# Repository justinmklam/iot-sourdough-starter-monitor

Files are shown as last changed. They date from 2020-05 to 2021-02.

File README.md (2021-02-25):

# IoT Sourdough Starter Monitor

Internet connected smart lid for sourdough starter. Tracks fermentation with distance, temperature, and humidity sensors, and publishes data to the cloud for further data logging and analysis.

Interested in more details? Read the full story on [justinmklam.com](https://www.justinmklam.com/posts/2021/02/levain-monitor/)!

<p align="center">
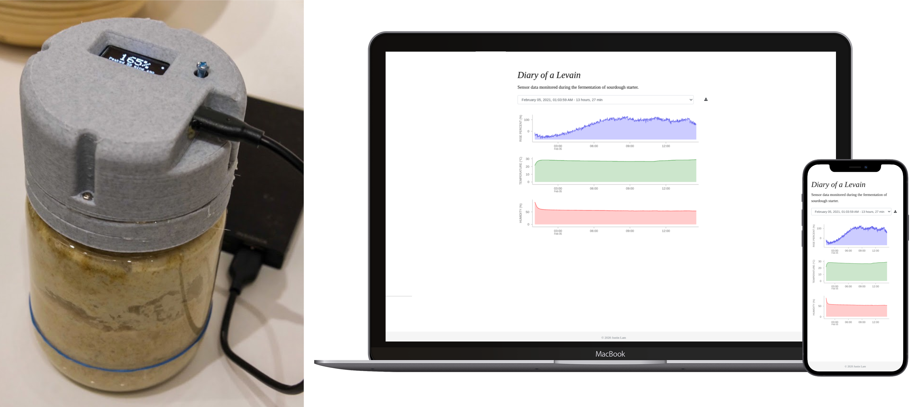
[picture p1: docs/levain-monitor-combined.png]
    <br>
    <i>Sourdough starter monitor (left), web application to view the logged data (right).</i>
</p>

<p align="center">
    <br>
    <i>Three modes of operation: Max rise and time, graph, stats for nerds.</i>
</p>

<p align="center">
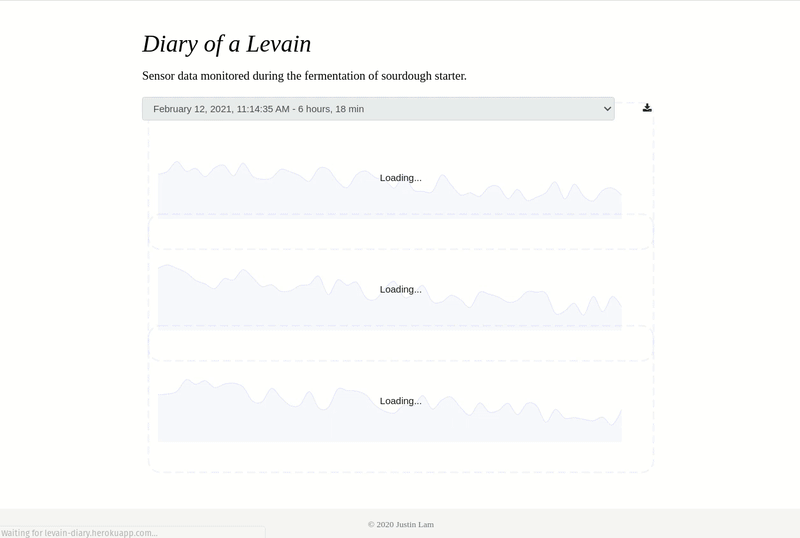
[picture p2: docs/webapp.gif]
    <br>
    <i>Selecting, viewing, and downloading data for a given feeding session.</i>
</p>

## Hardware

- NodeMCU ESP8266 (aka NodeMCU 1.0 ESP-12E)
- DHT22 Temperature and humidity sensor
- VL6180X Time of flight distance sensor
- SSD1306 Monochrome 128x32 I2C OLED display

<p align="center">
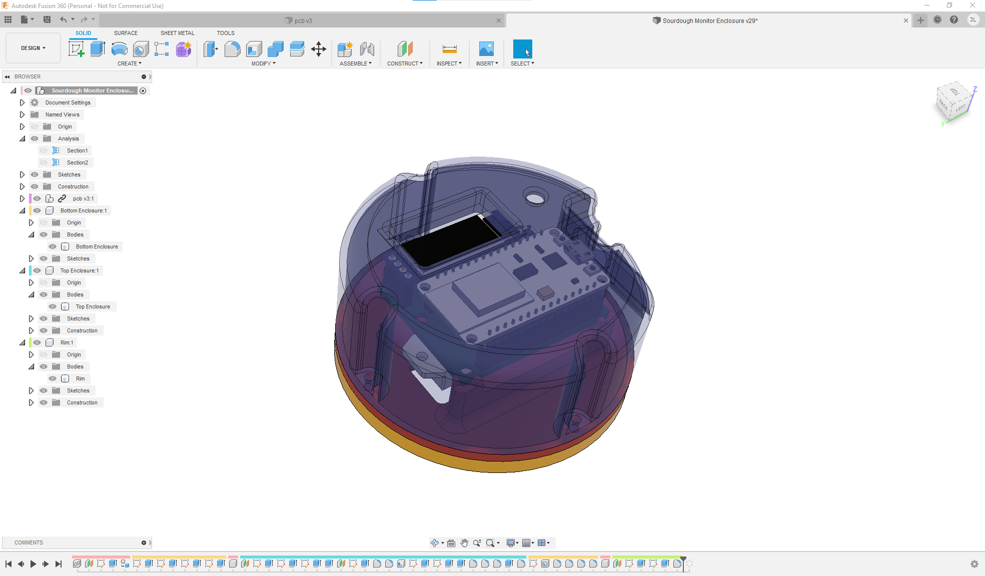
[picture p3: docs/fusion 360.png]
    <br>
    <i>3D printed enclosure (designed in Fusion 360).</i>
</p>

<p align="center">
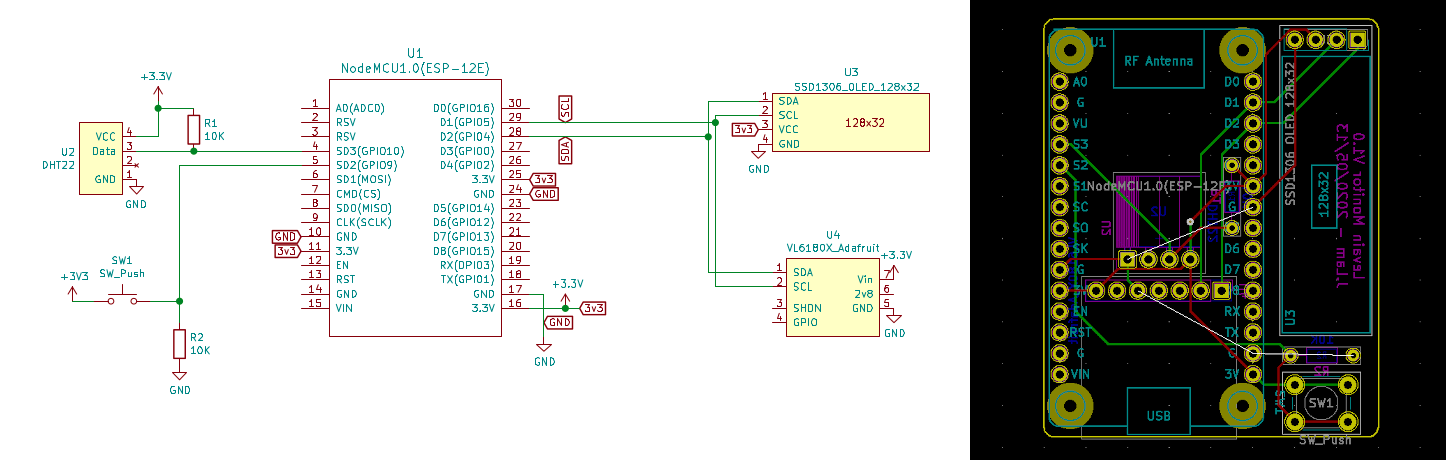
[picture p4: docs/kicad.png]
    <br>
    <i>PCB schematic and layout (designed in KiCad).</i>
</p>

<p align="center">
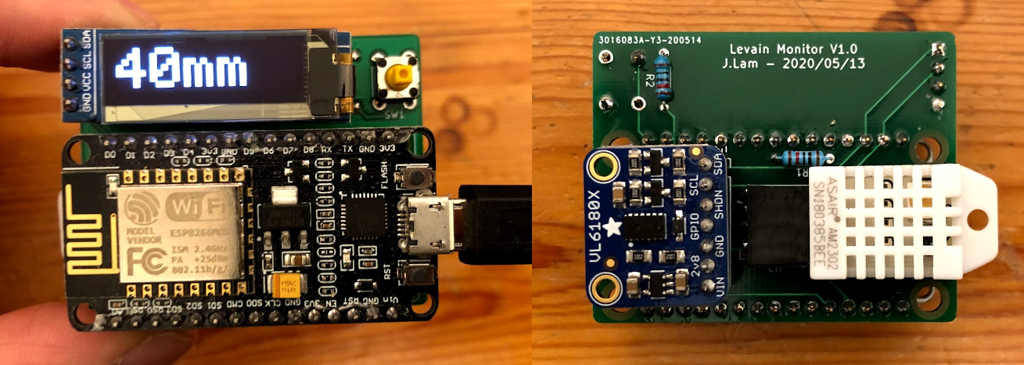
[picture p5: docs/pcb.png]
    <br>
    <i>Assembled PCB.</i>
</p>

## Software

AWS is used as the cloud backend. Data flow is as follows:

- ESP8266 sends sensor data over MQTT
- Kinesis Firehose receives data
- Lambda function puts data from Firehose to S3 on data receive event
- Web app queries S3 data via Athena

## Getting Started

### PlatformIO

This project is built using PlatformIO v5.1.0. To build:

```bash
# Build
pio run

# Build and upload
pio run -t upload
```

To view the serial monitor:

```bash
pio device monitor -b 115200
```

To run the tests:

```bash
# Run tests on device
pio test

# Run tests locally
pio test -e native
```

## Heroku

To deploy the web app to Heroku:

```
git subtree push --prefix webapp heroku master
```

## AWS IoT Certificates

Convert the certificates from AWS to `.der` files, then place them in `data/` (within the project directory).

```bash
openssl x509 -in xxx-certificate.pem.crt -out cert.der -outform DER
openssl rsa -in xxx-private.pem.key -out private.der -outform DER
openssl x509 -in AmazonRootCA1.pem -out ca.der -outform DER
```

Use the following command to upload the files to the SPIFFS filesystem:

```bash
pio run -t uploadfs
```

Alternatively, you may use the [arduino-esp8266fs-plugin](https://github.com/esp8266/arduino-esp8266fs-plugin) to upload the files.

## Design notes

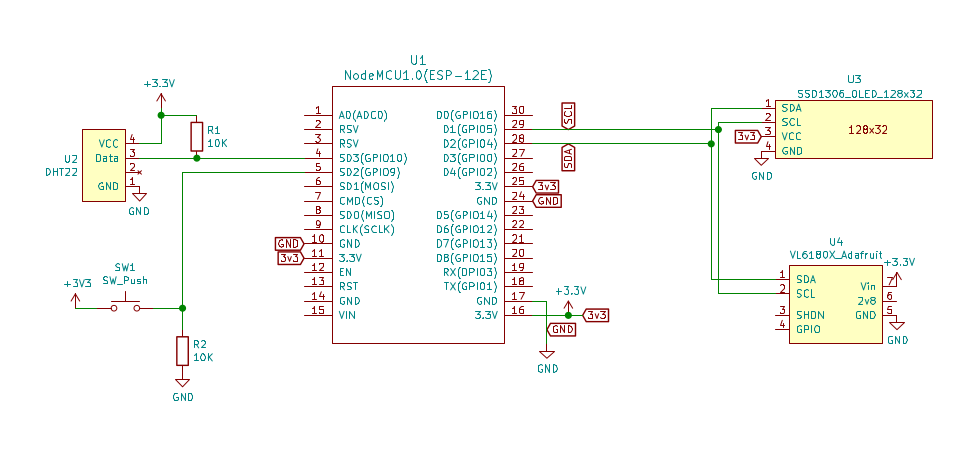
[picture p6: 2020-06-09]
docs/schematic.png

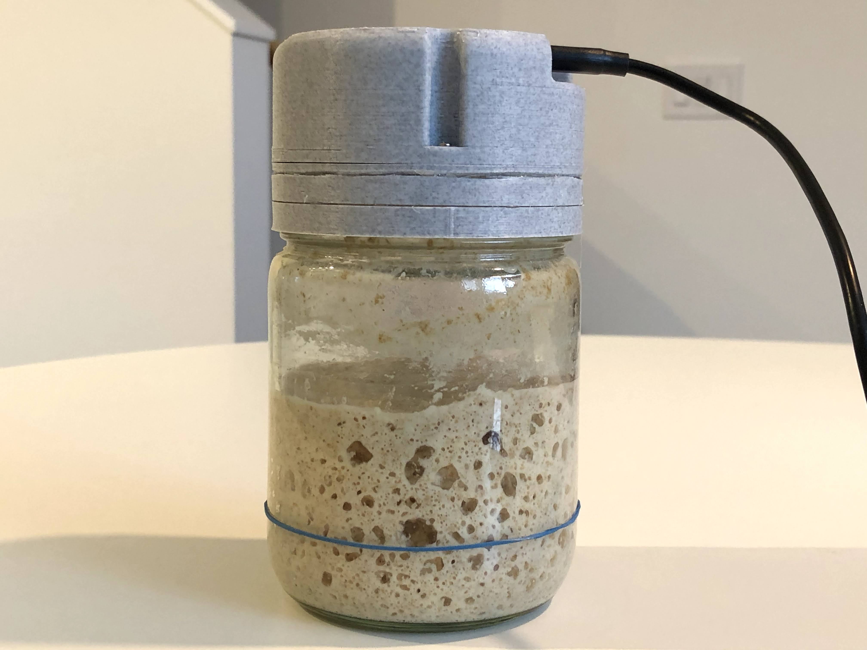
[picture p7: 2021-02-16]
docs/jar2.jpg

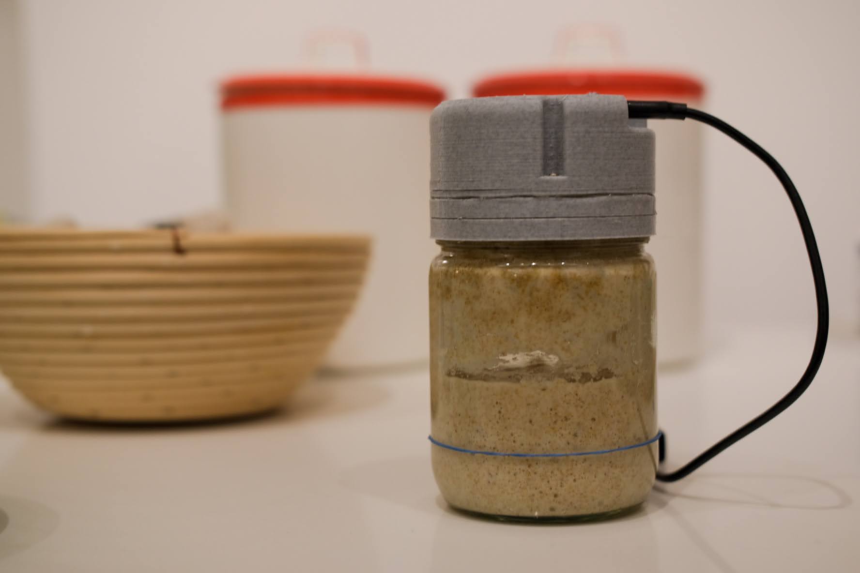
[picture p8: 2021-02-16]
docs/jar3.jpg

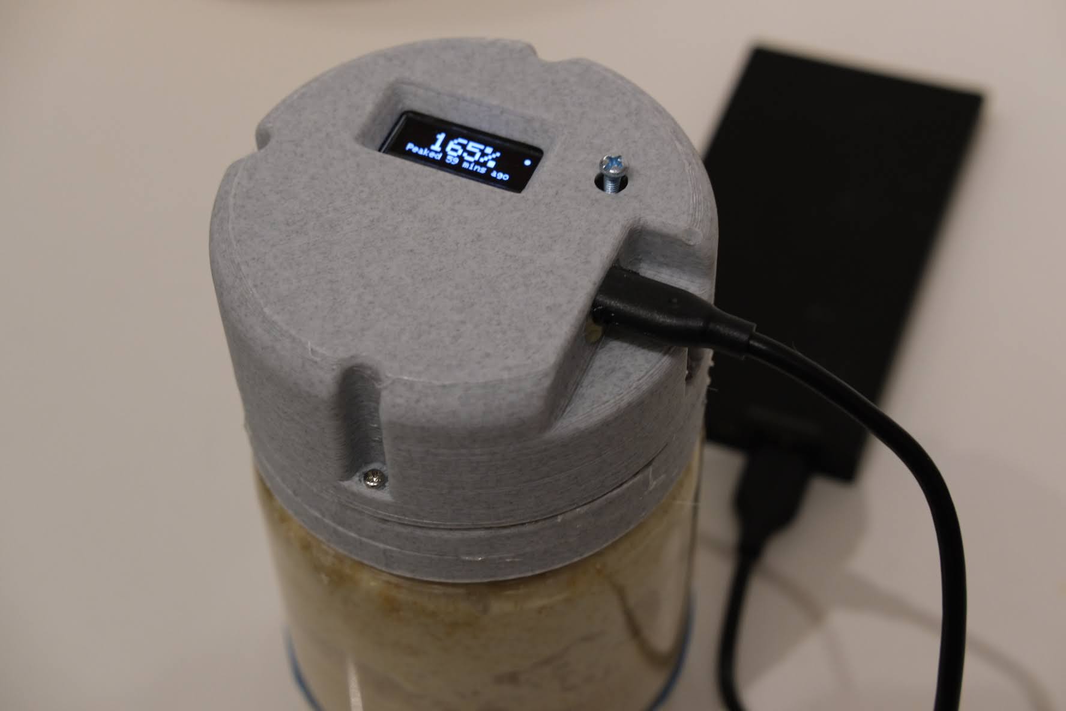
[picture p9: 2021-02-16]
docs/jar1.jpg

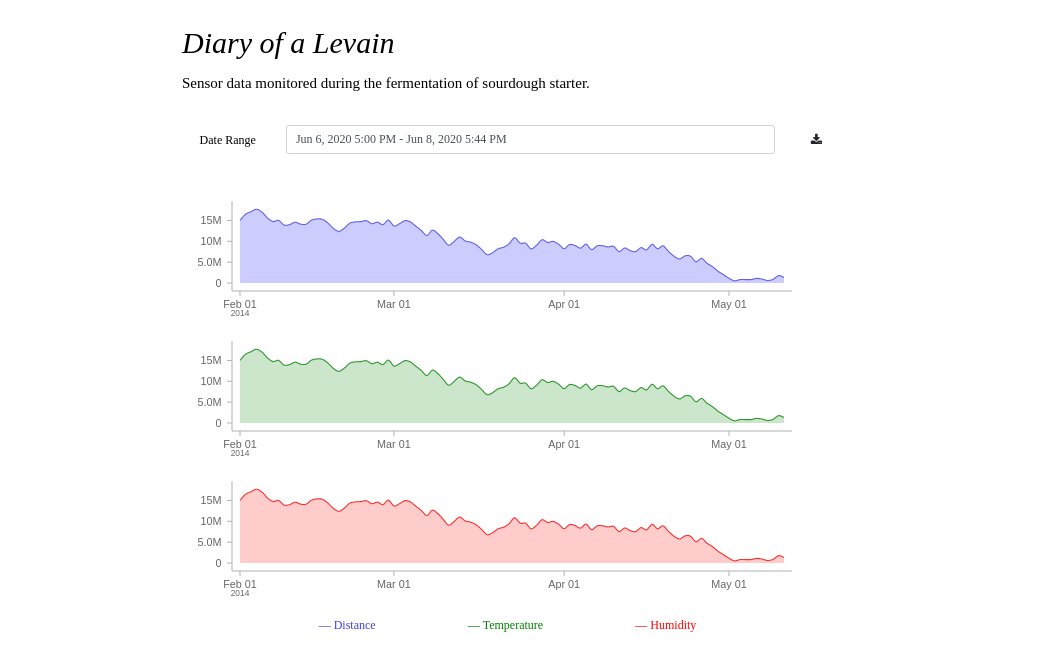
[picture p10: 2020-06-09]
docs/webapp.png

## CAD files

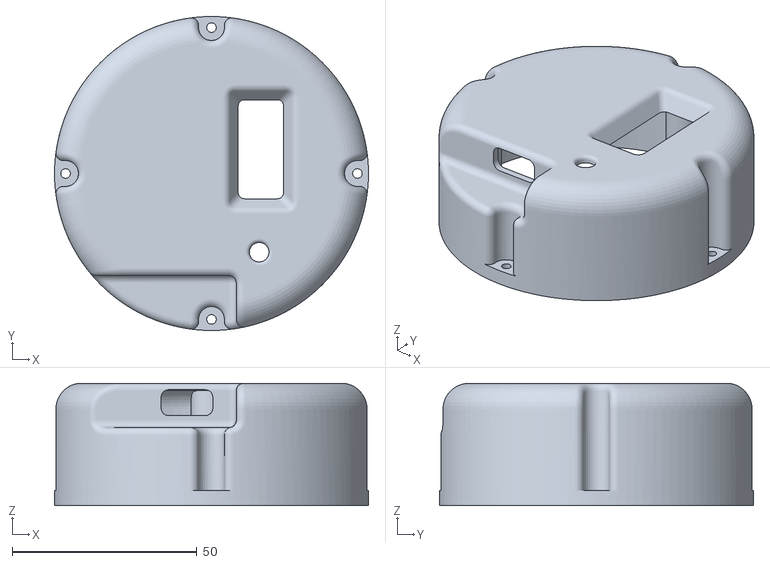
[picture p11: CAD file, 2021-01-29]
cad/Top Enclosure.stl
85.0 x 85.0 x 33.2

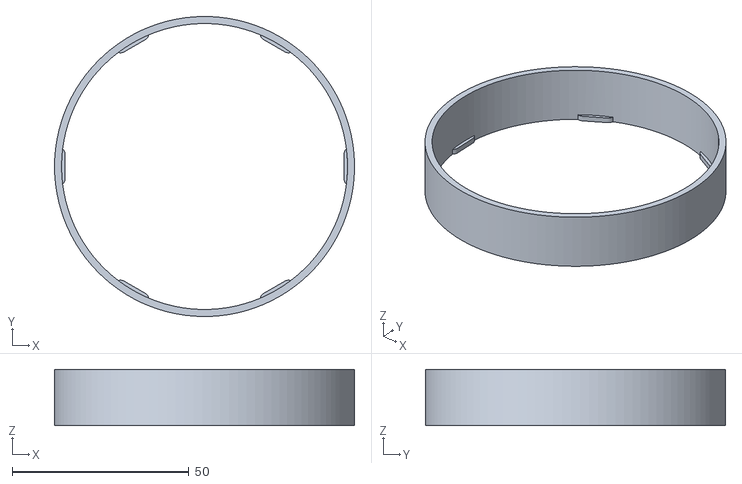
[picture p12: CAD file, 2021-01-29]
cad/Rim.stl
85.0 x 85.0 x 16.0

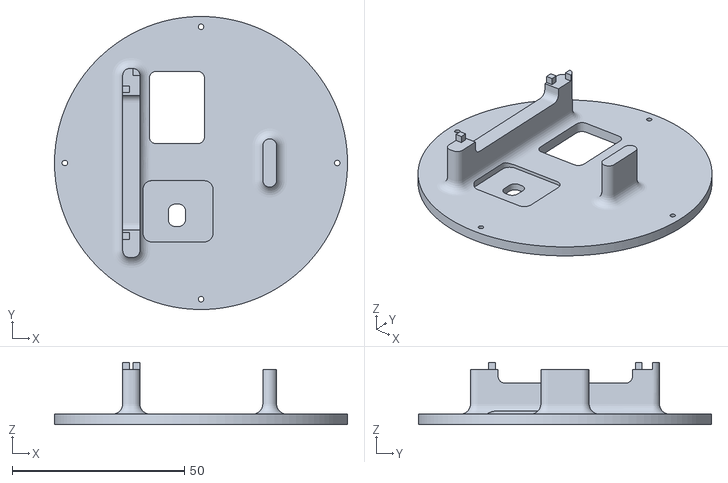
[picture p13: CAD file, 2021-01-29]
cad/Bottom Enclosure.stl
85.0 x 85.0 x 18.0

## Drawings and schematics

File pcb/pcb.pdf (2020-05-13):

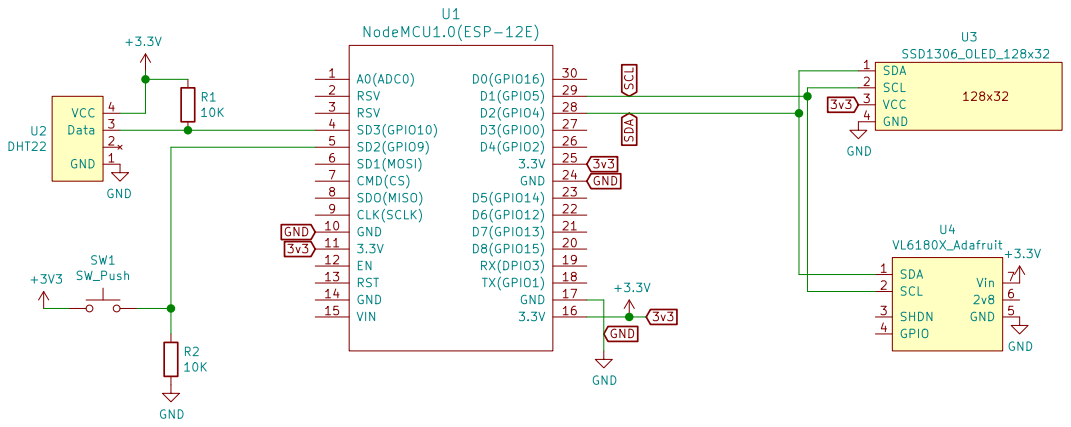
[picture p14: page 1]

File: pcb.sch Sheet: /
Id: 1/1 Title: Levain Monitor

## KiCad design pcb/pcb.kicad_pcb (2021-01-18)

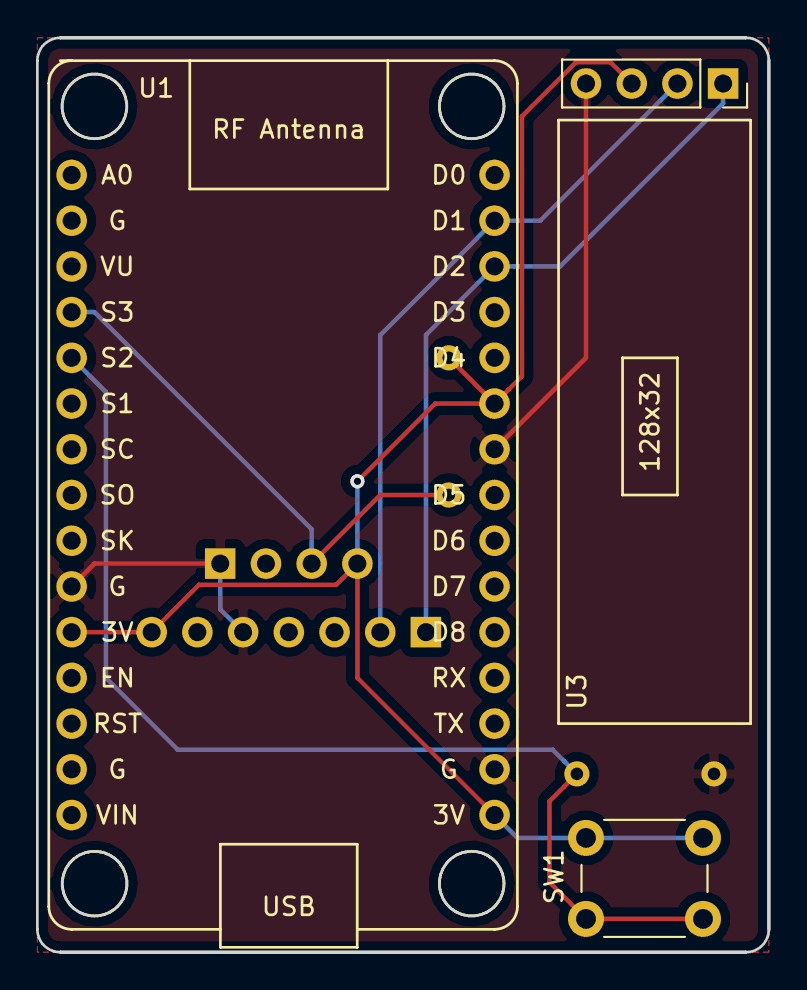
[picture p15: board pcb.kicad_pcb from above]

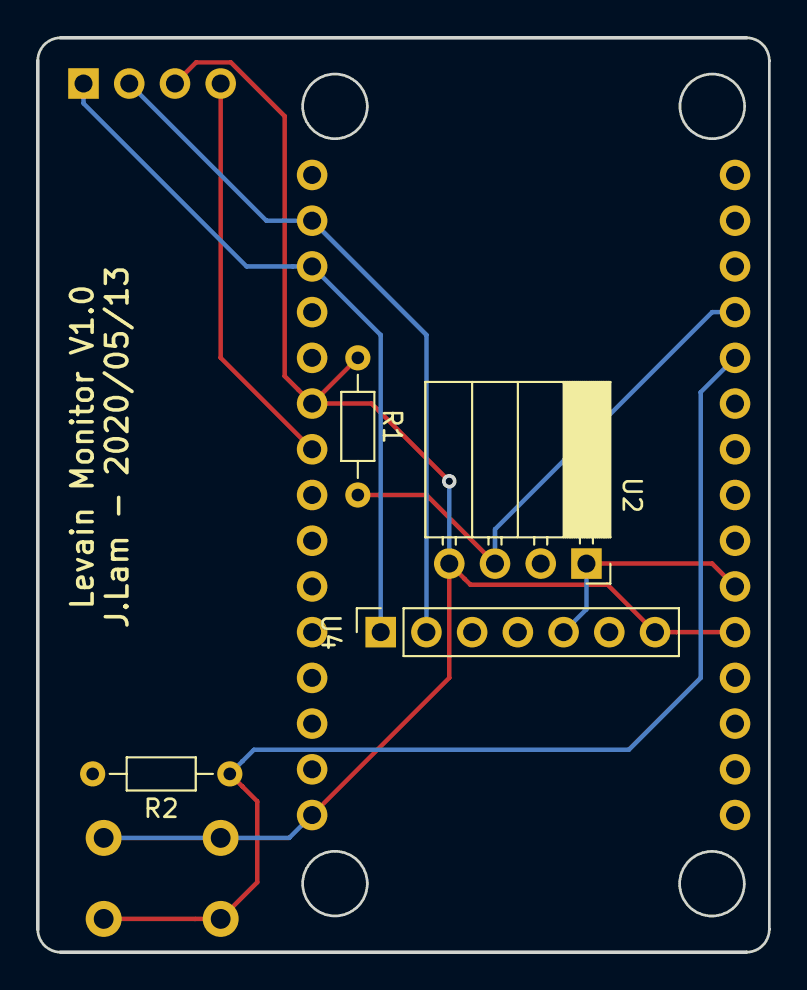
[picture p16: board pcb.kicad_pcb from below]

Board: 2 copper layers, 40.6 x 50.8 mm, 7 parts (4 on the bottom side), 6 nets.

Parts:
R1, R2: 10K; R_Axial_DIN0204_L3.6mm_D1.6mm_P7.62mm_Horizontal
SW1: SW_Push; SW_PUSH_6mm
U1: NodeMCU1.0(ESP-12E); ESP12F-Devkit-V3
U2: DHT22; PinSocket_1x04_P2.54mm_Horizontal
U3: SSD1306_OLED_128x32; SSD1306_Adafruit_128x32
U4: VL6180X_Adafruit

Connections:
3v3: R1.1, SW1.1, U1.11, U1.16, U1.25, U2.4, U3.3, U4.7
GND: R2.2, U1.10, U1.17, U1.24, U2.1, U3.4, U4.5
unnamed: R1.2, U1.4, U2.3
unnamed: R2.1, SW1.2, U1.5
SCL: U1.29, U3.2, U4.2
SDA: U1.28, U3.1, U4.1

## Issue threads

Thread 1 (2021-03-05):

Can you help me understand the process to get the pcbs made?

duhduhmknice, 2021-03-05:
I had a pcb made before but I don't remember how to do it. What files I need and how to begin. Thanks if you can help.

justinmklam, 2021-06-03:
PCB files are [here](https://github.com/justinmklam/iot-sourdough-starter-monitor/tree/master/pcb), and you can find instructions on how to send them to a fab shop [here](https://docs.oshpark.com/design-tools/kicad/generating-kicad-gerbers/).

Closed 2021-06-03.

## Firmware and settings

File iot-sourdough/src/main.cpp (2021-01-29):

#include <TaskScheduler.h>

#include "display.h"
#include "measurements.h"
#include "userinput.h"

// If false, device will be standalone/offline
#define ENABLE_IOT true

#if ENABLE_IOT
#include "iot.h"
Task tIoT(10, TASK_FOREVER, &tIoTCallback);
#endif
Task tMeasure(100, TASK_FOREVER, &tMeasureCallback);
Task tDisplay(250, TASK_FOREVER, &tDisplayCallback);
Task tUserInput(10, TASK_FOREVER, &tUserInputCallback);

Scheduler taskManager;

void setup()
{
  Serial.begin(115200);
  Serial.println("AWS Levain Monitor");
  delay(100);

  initializeMeasurements();
  initializeDisplay();
  initializeButton();

  taskManager.init();
#if ENABLE_IOT
  initializeIoT();
  taskManager.addTask(tIoT);
  tIoT.enable();
#endif
  taskManager.addTask(tMeasure);
  taskManager.addTask(tDisplay);
  taskManager.addTask(tUserInput);
  tMeasure.enable();
  tDisplay.enable();
  tUserInput.enable();
}

void loop()
{
  taskManager.execute();
}

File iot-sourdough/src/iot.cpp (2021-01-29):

#include <AWS.h>
#include <NTP.h>
#include <ESP8266WiFi.h>
#include <ArduinoJson.h>

#include "userinput.h"
#include "measurements.h"
#include "secrets.h"

#define PUBLISH_INTERVAL_MS 60000
#define WIFI_CONNECTION_TIMEOUT_MS 60000
#define LED_PIN D4

extern Measurements measurements;

AwsIot awsClient;
bool offline_mode = false;
bool wifi_connected = false;

void ledOn()
{
  digitalWrite(LED_PIN, LOW);
}

void ledOff()
{
  digitalWrite(LED_PIN, HIGH);
}

bool waitUntilWifiConnected(String message)
{
  Serial.print(message);

  long start_time = millis();
  bool is_wifi_connected = true;

  while (WiFi.status() != WL_CONNECTED)
  {
    if (millis() - start_time > WIFI_CONNECTION_TIMEOUT_MS)
    {
      offline_mode = true;
      is_wifi_connected = false;
      break;
    }
    Serial.print(".");
    delay(1000);
  }

  if (is_wifi_connected)
  {
    Serial.println("ok!");
  }
  else
  {
    Serial.println("timed out");
  }

  return is_wifi_connected;
}

void messageReceivedCallback(char *topic, byte *payload, unsigned int length)
{
  Serial.print("Received [");
  Serial.print(topic);
  Serial.print("]: ");

  for (int i = 0; i < length; i++)
  {
    Serial.print((char)payload[i]);
  }

  Serial.println();
}

void initializeIoT()
{
  pinMode(LED_PIN, OUTPUT);
  ledOff();

  WiFi.hostname("levain-monitor");
  WiFi.mode(WIFI_STA);
  WiFi.begin(ssid, pass);
  wifi_connected = waitUntilWifiConnected("Attempting to connect to SSID: " + String(ssid));

  if (offline_mode)
  {
    Serial.println("Wifi not connected. Starting in offline mode.");
    return;
  }
  else
  {
    ledOn();
  }

  // Pacific standard time = UTC -7
  configTimeWithNTP(-7, false);

  awsClient.setThingname("levain-monitor");
  awsClient.setPublishTopic("esp8266/data");
  awsClient.setHost("a292sjcsigiv8t-ats.iot.us-west-2.amazonaws.com");

#if LOAD_KEYS_FROM_SPIFFS
  awsClient.loadCertificatesFromSPIFFS();
#else
  // Load from hardcoded keys
  BearSSL::X509List cert(cacert);
  BearSSL::X509List client_crt(client_cert);
  BearSSL::PrivateKey key(privkey);
  awsClient.loadCertificates(&cert, &client_crt, &key);
#endif

  // Optional
  awsClient.setShadowTopic("$aws/things/levain-monitor/shadow/update");
  // awsClient.setSubscribeTopic("$aws/things/levain-monitor/shadow/update");
  // awsClient.setCallback(messageReceivedCallback);

  awsClient.connect();

  Serial.println("IoT initialization success");
  ledOff();
}

void tIoTCallback()
{
  if (offline_mode)
  {
    return;
  }

  static bool publishSuccess = false;
  static int numRetries = 0;
  static long prevMillis = millis();

  if (!wifi_connected)
  {
    waitUntilWifiConnected("Reconnecting to " + String(ssid));
  }

  if (!awsClient.connected())
  {
    Serial.println("MQTT disconnected, reconnecting now.");
    awsClient.connect();
  }

  if (getState() == STATE_MONITOR && millis() - prevMillis > PUBLISH_INTERVAL_MS)
  {
    ledOn();

    StaticJsonDocument<200> publishMessage;

    publishMessage["deviceId"] = measurements.deviceId;
    publishMessage["sessionId"] = measurements.sessionId;
    publishMessage["temperature"] = measurements.temperature;
    publishMessage["humidity"] = measurements.humidity;
    publishMessage["riseHeight"] = measurements.rise_height;
    publishMessage["risePercent"] = measurements.rise_percent;

    publishSuccess = awsClient.publishMessage(publishMessage);

    if (publishSuccess)
    {
      ledOff();
    }
    else
    {
      Serial.println("ERROR: Couldn't publish message");
    }
    prevMillis = millis();
  }

  awsClient.loop();
}

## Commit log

2020-04-20 Add working example of device shadow update
2020-04-20 Refactor; remove ESP32 references
2020-04-20 Remove ArduinoJSON library dependency
2020-04-20 Minor changes to device shadow update
2020-04-22 Publish to data topic for firehose injestion
    Also bring back ArduinoJson since it simplifiies message creation
2020-04-26 Add methods to subscribe and update device shadow
2020-04-26 Refactor get current ASCII time method
2020-05-03 Add function to download current data
2020-05-11 Initial commit of pcb
    [pcb.kicad_pcb, pcb.sch]
2020-05-12 Add kicad backup files to gitignore
2020-05-12 First PCB revision complete
    [pcb.kicad_pcb, pcb.sch]
2020-05-12 Add board outline
    [pcb.kicad_pcb]
2020-05-12 Move sensors down; fix routing
    [pcb.kicad_pcb]
2020-05-12 Add push button
    [pcb.kicad_pcb, pcb.sch]
2020-05-12 Correct display footprint to right size
    [pcb.kicad_pcb, pcb.sch]
2020-05-12 Use the right ESP8266 footprint
    [pcb.kicad_pcb, pcb.sch]
2020-05-12 Add gerbers and drill table
    [pcb-B.Cu.gbr, pcb-B.Mask.gbr, pcb-B.SilkS.gbr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]
2020-05-13 Add exposed FR4 to mounting holes
    [pcb.kicad_pcb]
2020-05-13 Add ground plane
    [pcb.kicad_pcb]
2020-05-13 Minor changes before gerber export
    [pcb.kicad_pcb]
2020-05-13 Update gerbers
    [pcb-B.Cu.gbr, pcb-B.Mask.gbr, pcb-B.SilkS.gbr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]
2020-05-13 Update schematic title block
    [pcb.sch]
2020-05-13 Export schematic to PDF
2020-05-14 Fix hole sizes on ESP8266 footprint
    [pcb.kicad_pcb]
2020-05-14 Export gerbers
    [pcb-B.Cu.gbr, pcb-B.Mask.gbr, pcb-B.SilkS.gbr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]
2020-05-14 Fix track/pad clearance after hole resize
    [pcb-B.Cu.gbr, pcb-B.Mask.gbr, pcb-B.SilkS.gbr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]
2020-05-30 Add VL6180X sensor to AWS
2020-05-30 Add DHT sensor to AWS
2020-11-20 Rename arduino project directory
2020-11-20 Add test framework
2020-11-23 Add user button task
2020-11-23 Differentiate short and long button press
2020-11-24 Add logic for while button is being pressed
2020-11-24 Rename button task to userinput task
2020-11-24 Add jar height calibration mode
2020-11-26 Actually fix rise height percent calculation
    [measurements.cpp]
2020-11-27 Add button callbacks
2020-11-27 Replace EasyButton with OneButton
    Handles single and double click at the same time
    [userinput.cpp]
2020-11-27 Switch behaviour of clicks and long press
2020-11-27 Only enter calibration state if not monitoring
2020-11-27 Populate advanced dashboard; fix floats/ints
    [measurements.cpp]
2020-12-07 Keep track of time since maximum height
2020-12-08 Show time since max instead of current rise
2021-01-02 Add session and device id to measurements
2021-01-02 Enable IoT thread, extend task delay to 10s
2021-01-02 Use onboard LED to show wifi status
2021-01-18 Add 3D models to components and export STEP file of PCB
    [pcb.kicad_pcb]
2021-01-18 Initial commit of enclosure files
    [Bottom Enclosure.stl, Rim.stl, Top Enclosure.stl]
2021-01-20 Only flash LED when sending message to aws
2021-01-21 Replace legend with y axis labels
2021-01-21 Show error if publish isn't successful
    [iot.cpp]
2021-01-21 Refactor LED on/off
2021-01-21 Try reconnecting to mqtt if publish doesn't succeed
    Also remove shadow update now that mqtt can reconnect if disconnected
    [iot.cpp]
2021-01-22 Remove publish retries since it doesn't work
    [iot.cpp]
2021-01-22 Minor improvements to print publish message
2021-01-29 Minor changes to enclosure
    [Bottom Enclosure.stl, Rim.stl, Top Enclosure.stl]
